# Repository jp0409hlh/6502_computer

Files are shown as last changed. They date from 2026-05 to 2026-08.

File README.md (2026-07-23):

# JP6502 computer

Warning: This repo is still early in development

## Hardware
**Warning** : This section is still under development, do not expect anything to work.
This folder contains the schematics and pcb files for this project.
### main_computer
This folder constains the schematics and pcb files for the JP6502 motherboard.
### others
Future plans : Floppy disk controller expansion card, SD card interface expansion card, ESP32 network expansion card.

## Software
**Warning** : This section is still under development, do not expect anything to work.
This folder contains softwares I wrote for this computer, mainly the OS.

## Credits

+ [Ben eater](http://www.youtube.com/@BenEater) - for the 6502 Youtube series
+ [krallja](http://www.youtube.com/@krallja) - for the [tutorial](https://www.youtube.com/watch?v=0QleiL-WdyM) of interfacing the Tms9918
+ [Doctor Volt](http://www.youtube.com/@DoctorVolt) - for the [tutorial](https://www.youtube.com/watch?v=smgGB_CsXns) of how to connect the Tms9918 to an Arduino, which helped me test my chip
+ [tomcircuit](https://hackaday.io/hacker/1679-tomcircuit) - for the [design](https://hackaday.io/project/160851-tms9918-vdp-with-sram-video-memory) of tms9918 SRAM replacement 
+ [mike's software blog](https://mike42.me/blog/) - for the inspiration of the code for xmodem
+ [sillycowvalley](https://github.com/sillycowvalley) - for the inspiration the [kernel](https://github.com/sillycowvalley/Hopper) 
+ [r/beneater community](https://www.reddit.com/r/beneater/)

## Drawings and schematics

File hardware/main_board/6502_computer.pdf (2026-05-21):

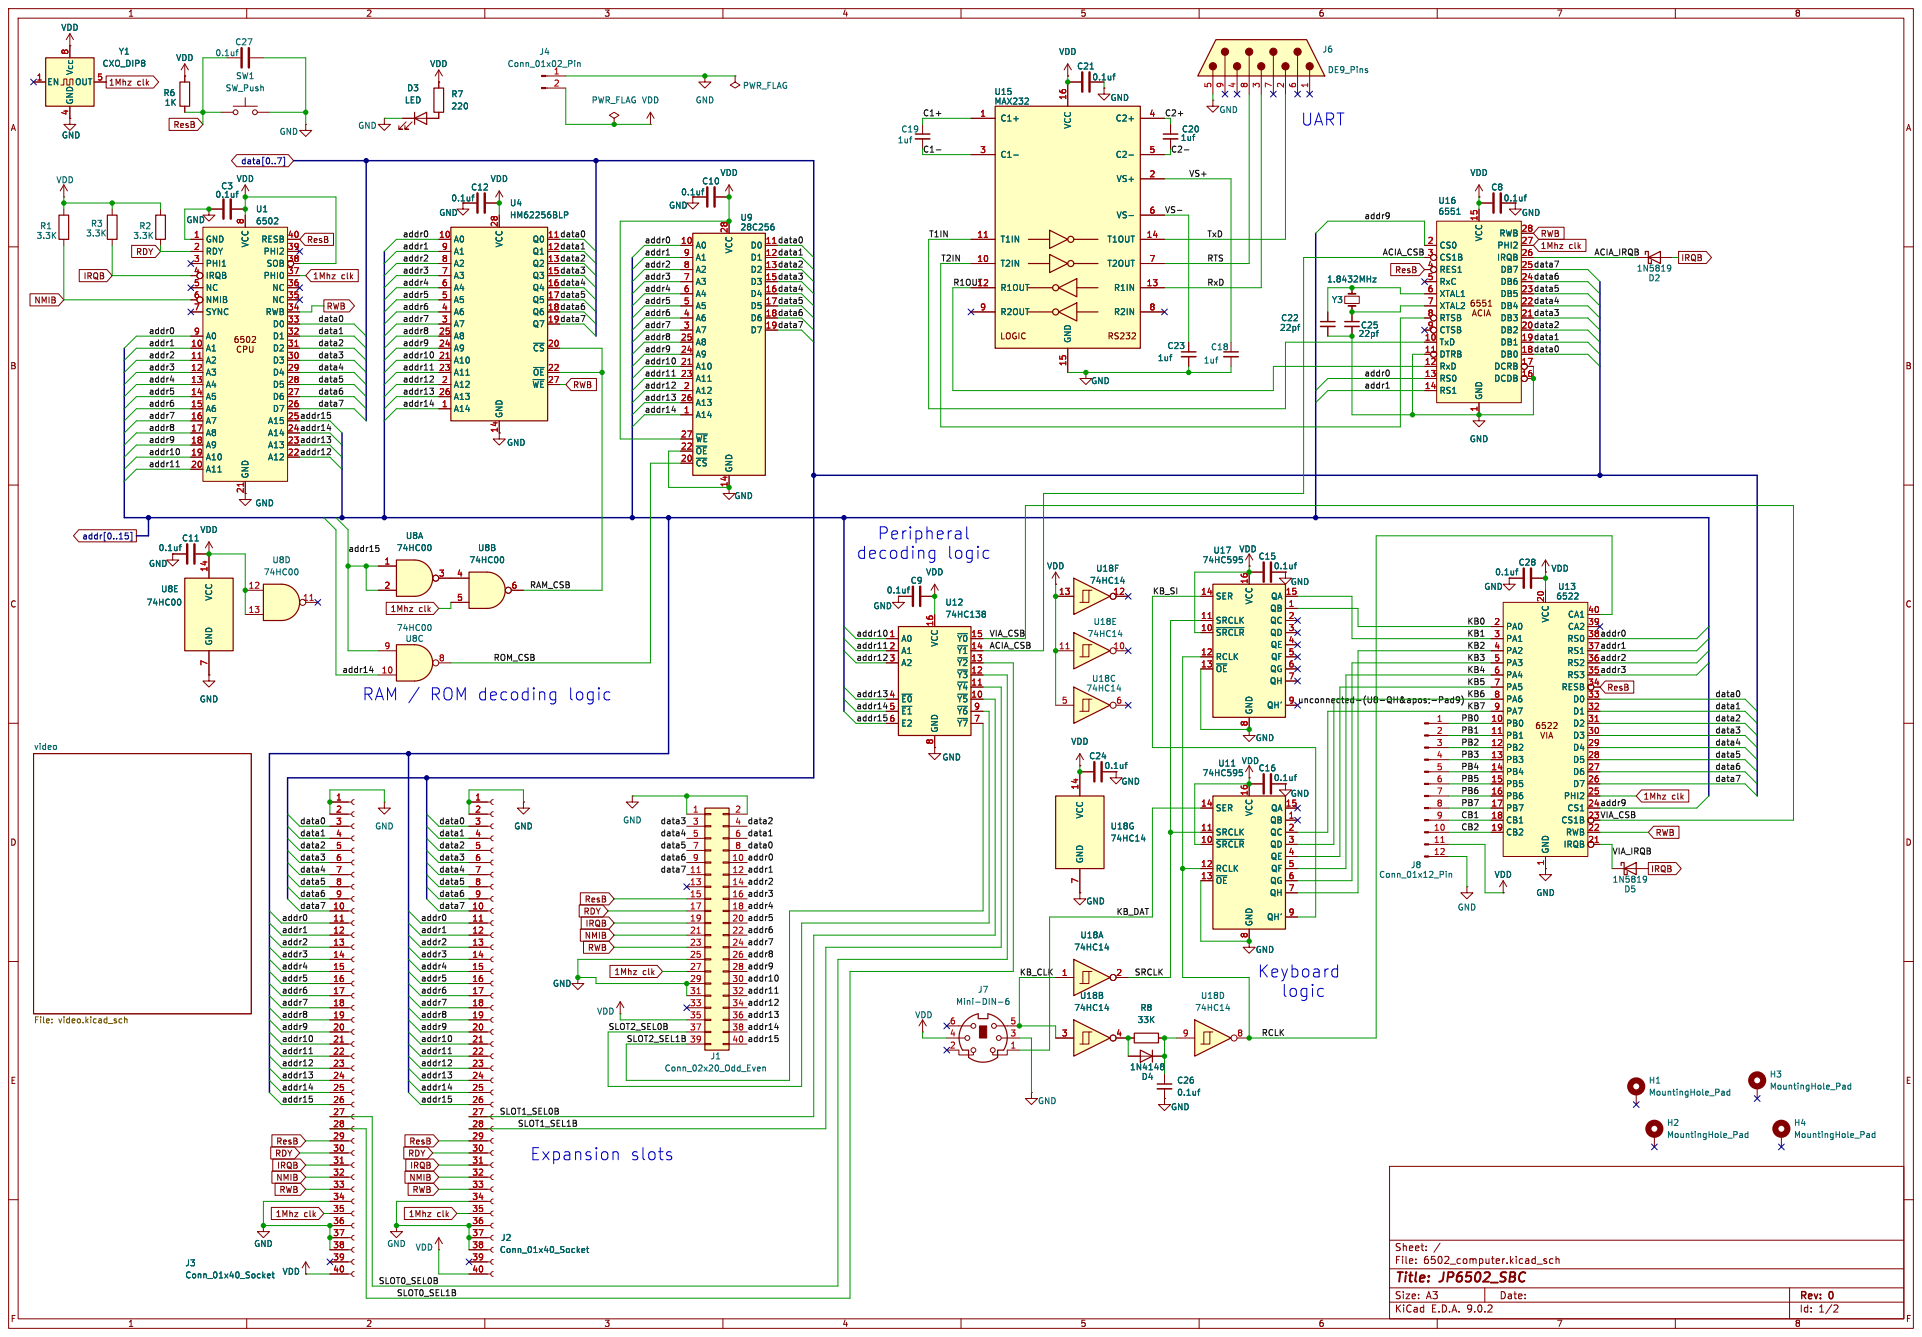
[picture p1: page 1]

8 GND 21 RESB 40 PHI2 39 SOB 38 PHI0 37 NC 36 NC 35 RWB 34 D0 33 D1 32 D2 31 D3 30 D4 29 D5 28 D6 27 D7 26 A15 25 A14 24 A13 23 A12 22 U1

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

8 QA 15 QB 1 QC 2 QD 3 QE 4 QF 5 QG 6 QH 7 QH' 9 GND

RAM / ROM decoding logic

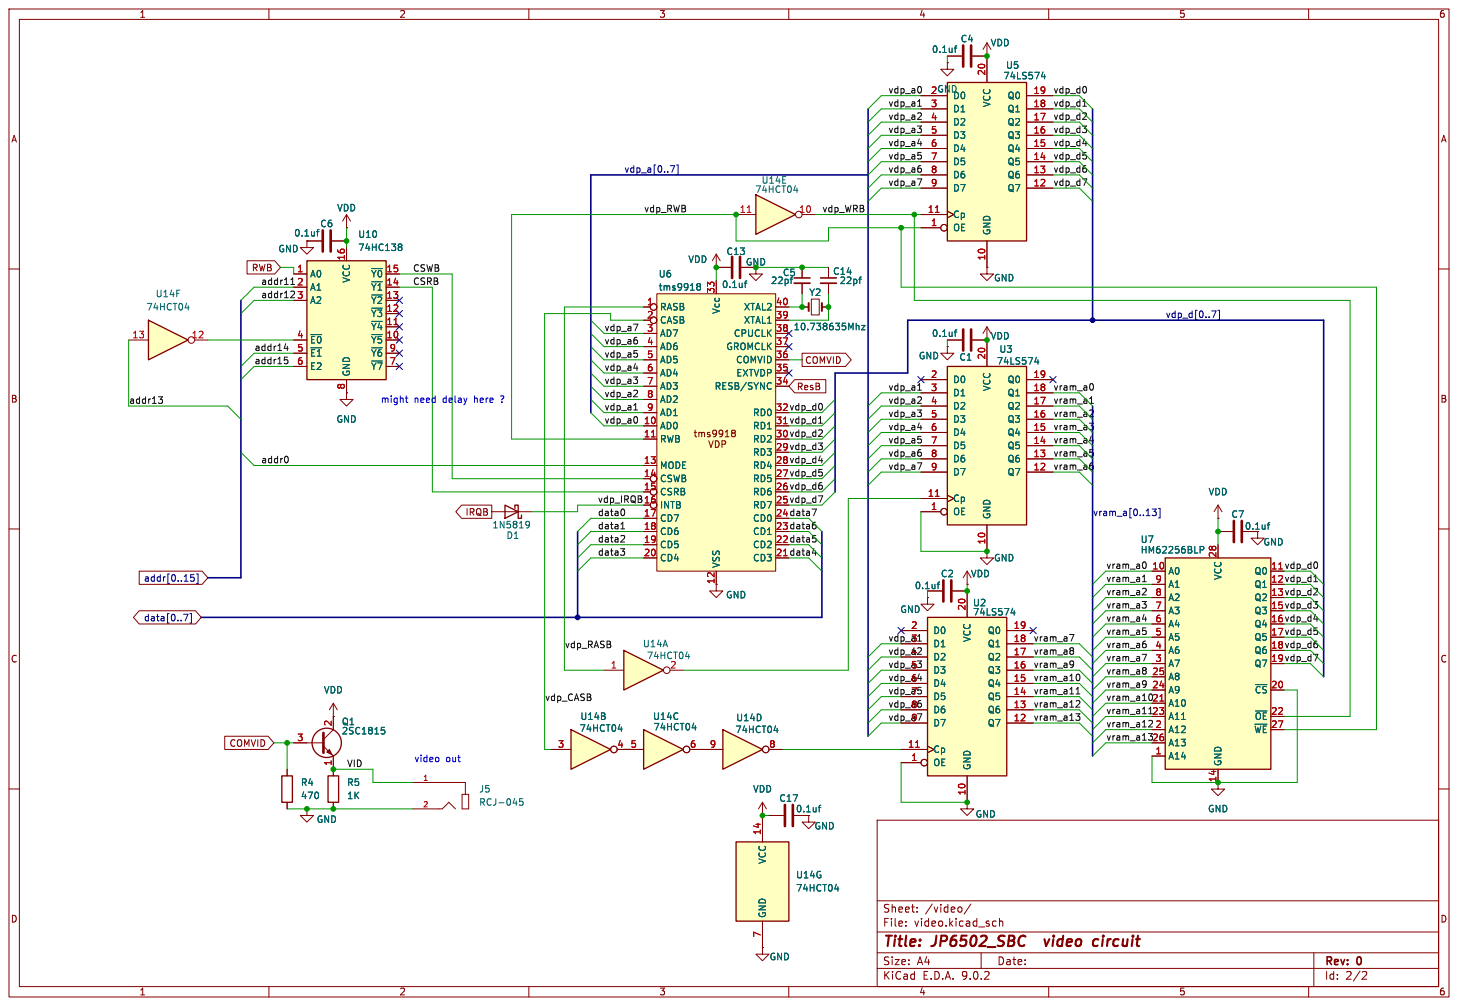
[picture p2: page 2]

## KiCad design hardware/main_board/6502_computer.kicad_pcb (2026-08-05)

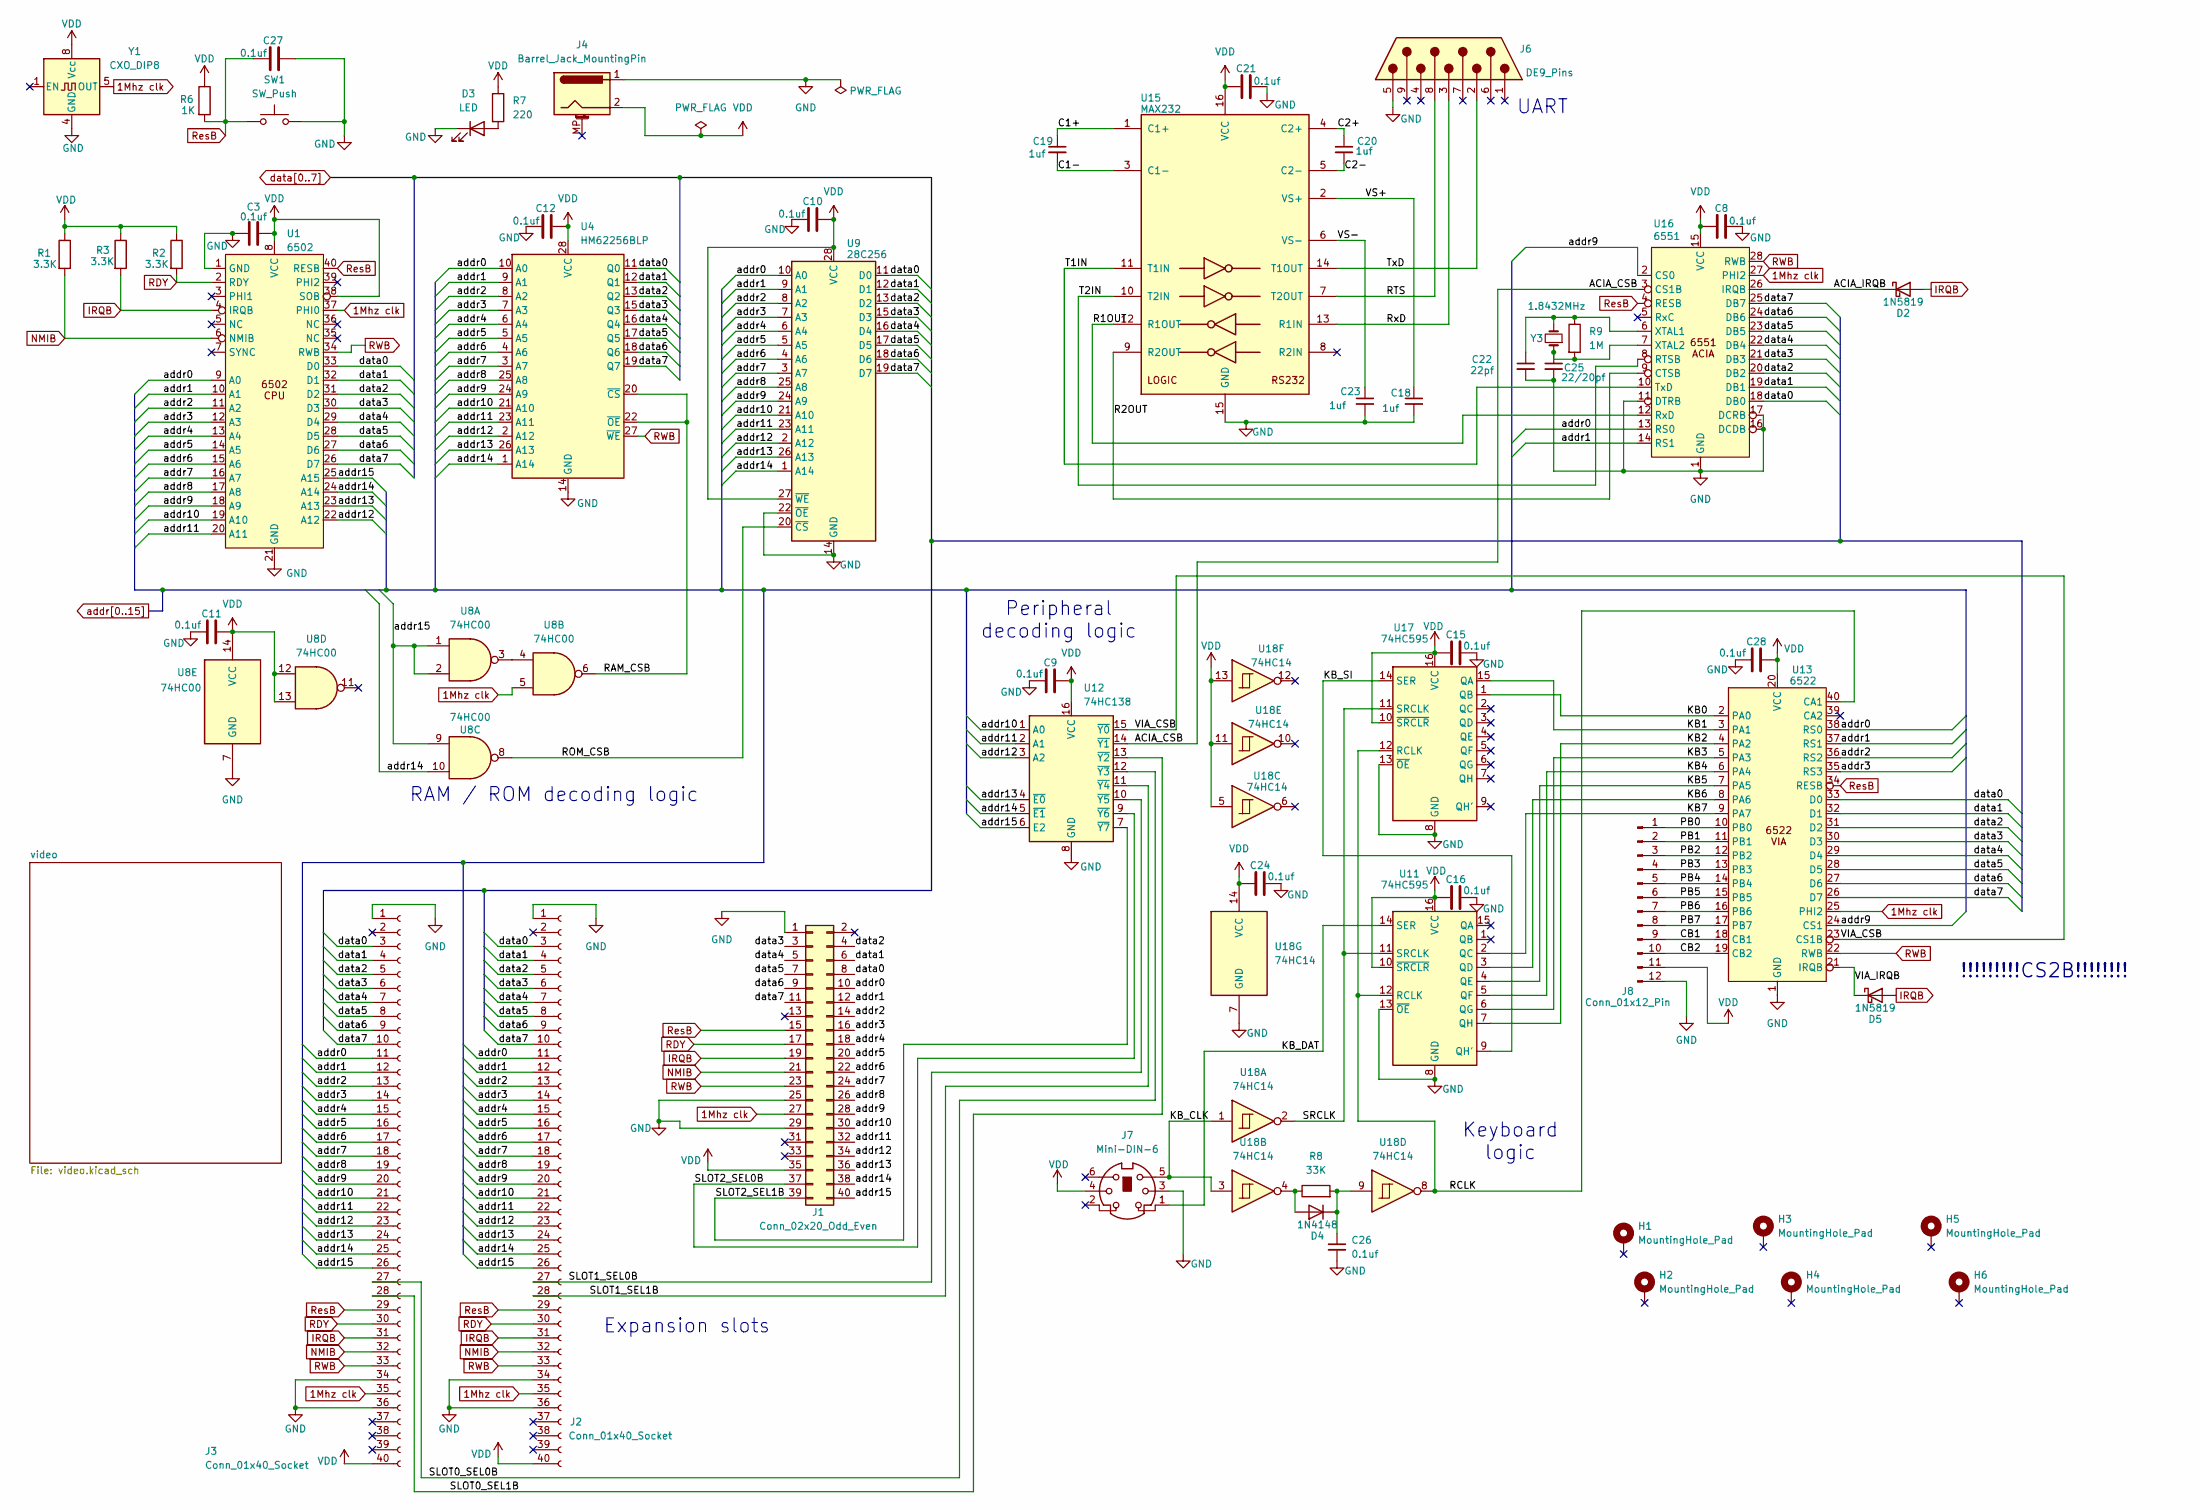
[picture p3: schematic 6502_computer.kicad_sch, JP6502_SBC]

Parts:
C3, C8, C9, C10, C11, C12, C15, C16, C21, C24, C26, C27, C28: 0.1uf; C_Disc_D5.0mm_W2.5mm_P2.50mm
C18, C19, C20, C23: 1uf; C_Disc_D5.1mm_W3.2mm_P5.00mm
C22: 22pf; C_Disc_D5.0mm_W2.5mm_P2.50mm
C25: 22/20pf; C_Disc_D5.0mm_W2.5mm_P2.50mm
D2, D5: 1N5819; D_DO-41_SOD81_P10.16mm_Horizontal
D3: LED; LED_D3.0mm
D4: 1N4148; D_DO-35_SOD27_P7.62mm_Horizontal
H1, H2, H3, H4, H5, H6: MountingHole_Pad; MountingHole_3.2mm_M3_ISO7380_Pad
J1: Conn_02x20_Odd_Even; IDC-Header_2x20_P2.54mm_Vertical
J2, J3: Conn_01x40_Socket; PinSocket_1x40_P2.54mm_Vertical
J4: Barrel_Jack_MountingPin; BarrelJack_Horizontal
J6: DE9_Pins; DSUB-9_Socket_Horizontal_P2.77x2.84mm_EdgePinOffset7.70mm_H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
J7: Mini-DIN-6; TE_5749180-1
J8: Conn_01x12_Pin; PinHeader_1x12_P2.54mm_Horizontal
R1, R2, R3: 3.3K; R_Axial_DIN0207_L6.3mm_D2.5mm_P10.16mm_Horizontal
R6: 1K; R_Axial_DIN0207_L6.3mm_D2.5mm_P10.16mm_Horizontal
R7: 220; R_Axial_DIN0207_L6.3mm_D2.5mm_P10.16mm_Horizontal
R8: 33K; R_Axial_DIN0207_L6.3mm_D2.5mm_P10.16mm_Horizontal
R9: 1M; R_Axial_DIN0207_L6.3mm_D2.5mm_P10.16mm_Horizontal
SW1: SW_Push; SW_PUSH_6mm_H8mm
U1: 6502; DIP-40_W15.24mm_Socket_LongPads
U4: HM62256BLP; DIP-28_W15.24mm_Socket_LongPads
U8: 74HC00; DIP-14_W7.62mm_Socket_LongPads
U9: 28C256; DIP_Socket-28_W11.9_W12.7_W15.24_W17.78_W18.5_3M_228-1277-0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
U11, U17: 74HC595; DIP-16_W7.62mm_Socket_LongPads
U12: 74HC138; DIP-16_W7.62mm_Socket_LongPads
U13: 6522; DIP-40_W15.24mm_Socket_LongPads
U15: MAX232; DIP-16_W7.62mm_Socket_LongPads
U16: 6551; DIP-28_W15.24mm_Socket_LongPads
U18: 74HC14; DIP-14_W7.62mm_Socket_LongPads
Y1: CXO_DIP8; Oscillator_DIP-8
Y3: 1.8432MHz; Crystal_HC18-U_Vertical

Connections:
1Mhz clk: J1.27, J2.35, J3.35, U1.37 (PHI0), U8.5, U13.25 (PHI2), U16.27 (PHI2), Y1.5 (OUT)
/ACIA_CSB: U12.14 (~Y1), U16.3 (CS1B)
/ACIA_IRQB: D2.1 (K), U16.26 (IRQB)
/C1+: C19.1, U15.1 (C1+)
/C1-: C19.2, U15.3 (C1-)
/C2+: C20.1, U15.4 (C2+)
/C2-: C20.2, U15.5 (C2-)
/CB1: J8.9, U13.18 (CB1)
/CB2: J8.10, U13.19 (CB2)
/KB0: U13.2 (PA0), U17.1 (QB)
/KB1: U13.3 (PA1), U17.15 (QA)
/KB2: U11.7 (QH), U13.4 (PA2)
/KB3: U11.6 (QG), U13.5 (PA3)
/KB4: U11.5 (QF), U13.6 (PA4)
/KB5: U11.4 (QE), U13.7 (PA5)
/KB6: U11.3 (QD), U13.8 (PA6)
/KB7: U11.2 (QC), U13.9 (PA7)
/KB_CLK: J7.5, U18.1, U18.3
/KB_DAT: J7.1, U11.14 (SER)
/KB_SI: U11.9 (QH'), U17.14 (SER)
/PB0: J8.1, U13.10 (PB0)
/PB1: J8.2, U13.11 (PB1)
/PB2: J8.3, U13.12 (PB2)
/PB3: J8.4, U13.13 (PB3)
/PB4: J8.5, U13.14 (PB4)
/PB5: J8.6, U13.15 (PB5)
/PB6: J8.7, U13.16 (PB6)
/PB7: J8.8, U13.17 (PB7)
/R1OUT: U15.12 (R1OUT), U16.12 (RxD)
/R2OUT: U15.9 (R2OUT), U16.9 (CTSB)
/RAM_CSB: U4.20 (~CS), U4.22 (~OE), U8.6
/RCLK: U11.12 (RCLK), U13.40 (CA1), U17.12 (RCLK), U18.8
/ROM_CSB: U8.8, U9.20 (~CS)
/RTS: J6.8, U15.7 (T2OUT)
/RxD: J6.3, U15.13 (R1IN)
/SLOT0_SEL0B: J3.27, U12.12 (~Y3)
/SLOT0_SEL1B: J3.28, U12.13 (~Y2)
/SLOT1_SEL0B: J2.27, U12.10 (~Y5)
/SLOT1_SEL1B: J2.28, U12.11 (~Y4)
/SLOT2_SEL0B: J1.37, U12.9 (~Y6)
/SLOT2_SEL1B: J1.39, U12.7 (~Y7)
/SRCLK: U11.11 (SRCLK), U17.11 (SRCLK), U18.2
/T1IN: U15.11 (T1IN), U16.10 (TxD)
/T2IN: U15.10 (T2IN), U16.8 (RTSB)
/TxD: J6.2, U15.14 (T1OUT)
/VIA_CSB: U12.15 (~Y0), U13.23 (CS1B)
/VIA_IRQB: D5.1 (K), U13.21 (IRQB)
/VS+: C18.1, U15.2 (VS+)
/VS-: C23.1, U15.6 (VS-)
GND: C3.1, C8.2, C9.1, C10.1, C11.1, C12.1, C15.2, C16.2, C18.2, C21.2, C22.2, C23.2, C24.2, C25.2, C26.2, C27.2, C28.1, D3.1 (K), J1.1, J1.25, J1.29, J2.1, J2.34, J2.36, J3.1, J3.34, J3.36, J4.1, J6.5, J7.3, J8.12, SW1.2, U1.1 (GND), U1.21 (GND), U4.14 (GND), U8.7 (GND), U9.14 (GND), U9.22 (~OE), U11.8 (GND), U11.13 (~OE), U12.8 (GND), U13.1 (GND), U15.15 (GND), U16.1 (GND), U16.11 (DTRB), U16.16 (DCDB), U16.17 (DCRB), U17.8 (GND), U17.13 (~OE), U18.7 (GND), Y1.4 (GND); also elsewhere on the board
IRQB: D2.2 (A), D5.2 (A), J1.19, J2.31, J3.31, R3.2, U1.4 (IRQB); also elsewhere on the board
NMIB: J1.21, J2.32, J3.32, R1.2, U1.6 (NMIB)
unnamed: D3.2 (A), R7.2
unnamed: D4.2 (A), R8.1, U18.4
unnamed: C26.1, D4.1 (K), R8.2, U18.9
unnamed: U8.3, U8.4
unnamed: C22.1, R9.1, U16.6 (XTAL1), Y3.2
unnamed: C25.1, R9.2, U16.7 (XTAL2), Y3.1
RDY: J1.17, J2.30, J3.30, R2.2, U1.2 (RDY)
RWB: J1.23, J2.33, J3.33, U1.34 (RWB), U4.27 (~WE), U13.22 (RWB), U16.28 (RWB); also elsewhere on the board
ResB: C27.1, J1.15, J2.29, J3.29, R6.2, SW1.1, U1.40 (RESB), U13.34 (RESB), U16.4 (RESB); also elsewhere on the board
VDD: C3.2, C8.1, C9.2, C10.2, C11.2, C12.2, C15.1, C16.1, C21.1, C24.1, C28.2, J1.35, J2.40, J3.40, J4.2, J7.4, J8.11, R1.1, R2.1, R3.1, R6.1, R7.1, U1.8 (VCC), U1.38 (SOB), U4.28 (VCC), U8.12, U8.13, U8.14 (VCC), U9.27 (~WE), U9.28 (VCC), U11.10 (~SRCLR), U11.16 (VCC), U12.16 (VCC), U13.20 (VCC), U15.16 (VCC), U16.15 (VCC), U17.10 (~SRCLR), U17.16 (VCC), U18.5, U18.11, U18.13, U18.14 (VCC), Y1.8 (Vcc); also elsewhere on the board
addr0: J1.10, J2.11, J3.11, U1.9 (A0), U4.10 (A0), U9.10 (A0), U13.38 (RS0), U16.13 (RS0); also elsewhere on the board
addr1: J1.12, J2.12, J3.12, U1.10 (A1), U4.9 (A1), U9.9 (A1), U13.37 (RS1), U16.14 (RS1)
addr2: J1.14, J2.13, J3.13, U1.11 (A2), U4.8 (A2), U9.8 (A2), U13.36 (RS2)
addr3: J1.16, J2.14, J3.14, U1.12 (A3), U4.7 (A3), U9.7 (A3), U13.35 (RS3)
addr4: J1.18, J2.15, J3.15, U1.13 (A4), U4.6 (A4), U9.6 (A4)
addr5: J1.20, J2.16, J3.16, U1.14 (A5), U4.5 (A5), U9.5 (A5)
addr6: J1.22, J2.17, J3.17, U1.15 (A6), U4.4 (A6), U9.4 (A6)
addr7: J1.24, J2.18, J3.18, U1.16 (A7), U4.3 (A7), U9.3 (A7)
addr8: J1.26, J2.19, J3.19, U1.17 (A8), U4.25 (A8), U9.25 (A8)
addr9: J1.28, J2.20, J3.20, U1.18 (A9), U4.24 (A9), U9.24 (A9), U13.24 (CS1), U16.2 (CS0)
addr10: J1.30, J2.21, J3.21, U1.19 (A10), U4.21 (A10), U9.21 (A10), U12.1 (A0)
addr11: J1.32, J2.22, J3.22, U1.20 (A11), U4.23 (A11), U9.23 (A11), U12.2 (A1); also elsewhere on the board
addr12: J1.34, J2.23, J3.23, U1.22 (A12), U4.2 (A12), U9.2 (A12), U12.3 (A2); also elsewhere on the board
addr13: J1.36, J2.24, J3.24, U1.23 (A13), U4.26 (A13), U9.26 (A13), U12.4 (~E0); also elsewhere on the board
addr14: J1.38, J2.25, J3.25, U1.24 (A14), U4.1 (A14), U8.10, U9.1 (A14), U12.5 (~E1); also elsewhere on the board
addr15: J1.40, J2.26, J3.26, U1.25 (A15), U8.1, U8.2, U8.9, U12.6 (E2); also elsewhere on the board
data0: J1.8, J2.3, J3.3, U1.33 (D0), U4.11 (Q0), U9.11 (D0), U13.33 (D0), U16.18 (DB0); also elsewhere on the board
data1: J1.6, J2.4, J3.4, U1.32 (D1), U4.12 (Q1), U9.12 (D1), U13.32 (D1), U16.19 (DB1); also elsewhere on the board
data2: J1.4, J2.5, J3.5, U1.31 (D2), U4.13 (Q2), U9.13 (D2), U13.31 (D2), U16.20 (DB2); also elsewhere on the board
data3: J1.3, J2.6, J3.6, U1.30 (D3), U4.15 (Q3), U9.15 (D3), U13.30 (D3), U16.21 (DB3); also elsewhere on the board
data4: J1.5, J2.7, J3.7, U1.29 (D4), U4.16 (Q4), U9.16 (D4), U13.29 (D4), U16.22 (DB4); also elsewhere on the board
data5: J1.7, J2.8, J3.8, U1.28 (D5), U4.17 (Q5), U9.17 (D5), U13.28 (D5), U16.23 (DB5); also elsewhere on the board
data6: J1.9, J2.9, J3.9, U1.27 (D6), U4.18 (Q6), U9.18 (D6), U13.27 (D6), U16.24 (DB6); also elsewhere on the board
data7: J1.11, J2.10, J3.10, U1.26 (D7), U4.19 (Q7), U9.19 (D7), U13.26 (D7), U16.25 (DB7); also elsewhere on the board

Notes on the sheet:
!!!!!!!!!CS2B!!!!!!!!
UART
RAM / ROM decoding logic
Expansion slots
Keyboard logic
Peripheral decoding logic

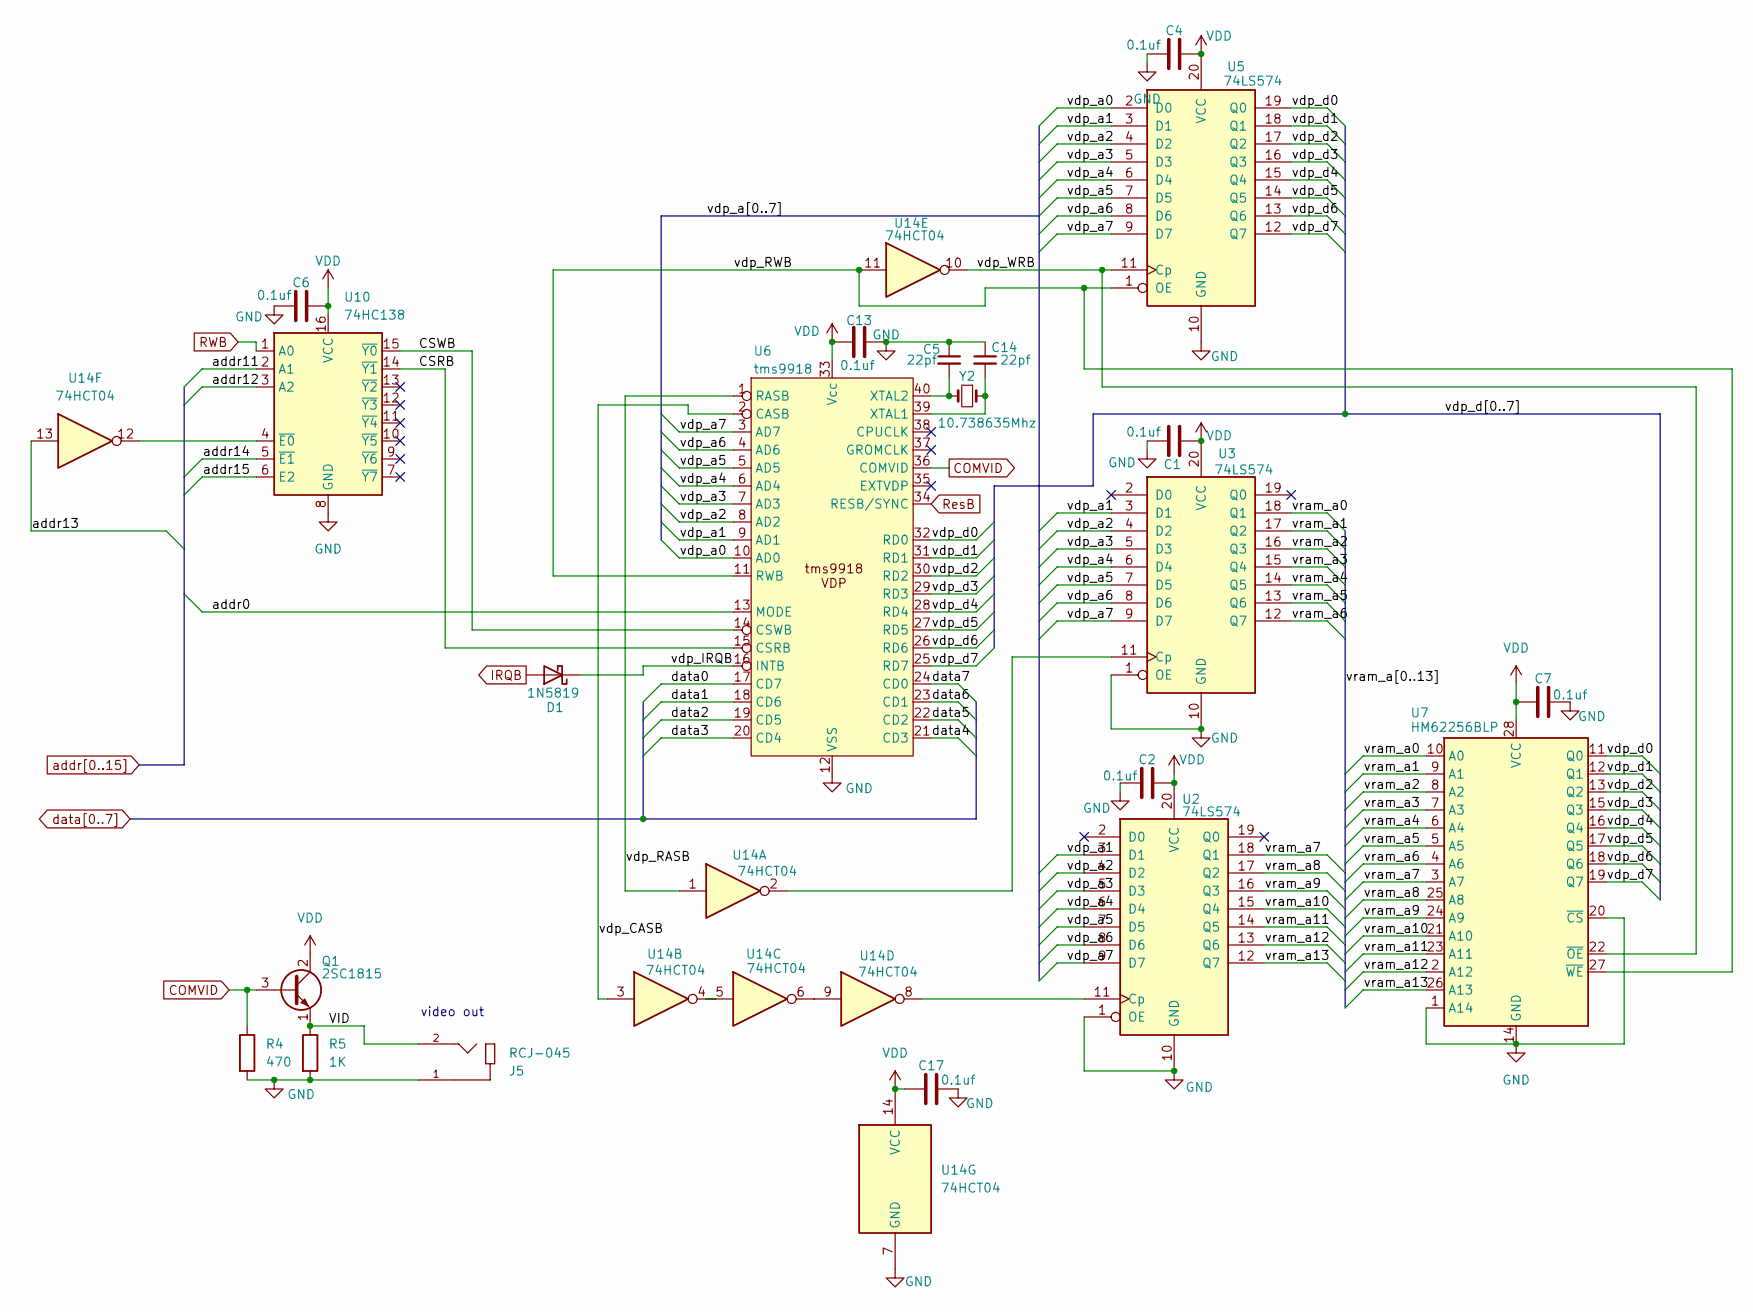
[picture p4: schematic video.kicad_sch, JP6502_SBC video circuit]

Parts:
C1, C2, C4, C6, C7, C13, C17: 0.1uf; C_Disc_D5.0mm_W2.5mm_P2.50mm
C5, C14: 22pf; C_Disc_D5.0mm_W2.5mm_P2.50mm
D1: 1N5819; D_DO-41_SOD81_P10.16mm_Horizontal
J5: RCJ-045; CUI_RCJ-045
Q1: 2SC1815; TO-92_HandSolder
R4: 470; R_Axial_DIN0207_L6.3mm_D2.5mm_P10.16mm_Horizontal
R5: 1K; R_Axial_DIN0207_L6.3mm_D2.5mm_P10.16mm_Horizontal
U2, U3, U5: 74LS574; DIP-20_W7.62mm_Socket_LongPads
U6: tms9918; DIP-40_W15.24mm_Socket_LongPads
U7: HM62256BLP; DIP-28_W15.24mm_LongPads
U10: 74HC138; DIP-16_W7.62mm_Socket_LongPads
U14: 74HCT04; DIP-14_W7.62mm_Socket_LongPads
Y2: 10.738635Mhz; Crystal_HC18-U_Vertical

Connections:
/video/CSRB: U6.15 (CSRB), U10.14 (~Y1)
/video/CSWB: U6.14 (CSWB), U10.15 (~Y0)
/video/VID: J5.2, Q1.1 (E), R5.1
/video/vdp_CASB: U6.2 (CASB), U14.3
/video/vdp_IRQB: D1.1 (K), U6.16 (INTB)
/video/vdp_RASB: U6.1 (RASB), U14.1
/video/vdp_RWB: U5.1 (OE), U6.11 (RWB), U7.27 (~WE), U14.11
/video/vdp_WRB: U5.11 (Cp), U7.22 (~OE), U14.10
/video/vdp_a0: U5.2 (D0), U6.10 (AD0)
/video/vdp_a1: U2.3 (D1), U3.3 (D1), U5.3 (D1), U6.9 (AD1)
/video/vdp_a2: U2.4 (D2), U3.4 (D2), U5.4 (D2), U6.8 (AD2)
/video/vdp_a3: U2.5 (D3), U3.5 (D3), U5.5 (D3), U6.7 (AD3)
/video/vdp_a4: U2.6 (D4), U3.6 (D4), U5.6 (D4), U6.6 (AD4)
/video/vdp_a5: U2.7 (D5), U3.7 (D5), U5.7 (D5), U6.5 (AD5)
/video/vdp_a6: U2.8 (D6), U3.8 (D6), U5.8 (D6), U6.4 (AD6)
/video/vdp_a7: U2.9 (D7), U3.9 (D7), U5.9 (D7), U6.3 (AD7)
/video/vdp_d0: U5.19 (Q0), U6.32 (RD0), U7.11 (Q0)
/video/vdp_d1: U5.18 (Q1), U6.31 (RD1), U7.12 (Q1)
/video/vdp_d2: U5.17 (Q2), U6.30 (RD2), U7.13 (Q2)
/video/vdp_d3: U5.16 (Q3), U6.29 (RD3), U7.15 (Q3)
/video/vdp_d4: U5.15 (Q4), U6.28 (RD4), U7.16 (Q4)
/video/vdp_d5: U5.14 (Q5), U6.27 (RD5), U7.17 (Q5)
/video/vdp_d6: U5.13 (Q6), U6.26 (RD6), U7.18 (Q6)
/video/vdp_d7: U5.12 (Q7), U6.25 (RD7), U7.19 (Q7)
/video/vram_a0: U3.18 (Q1), U7.10 (A0)
/video/vram_a1: U3.17 (Q2), U7.9 (A1)
/video/vram_a2: U3.16 (Q3), U7.8 (A2)
/video/vram_a3: U3.15 (Q4), U7.7 (A3)
/video/vram_a4: U3.14 (Q5), U7.6 (A4)
/video/vram_a5: U3.13 (Q6), U7.5 (A5)
/video/vram_a6: U3.12 (Q7), U7.4 (A6)
/video/vram_a7: U2.18 (Q1), U7.3 (A7)
/video/vram_a8: U2.17 (Q2), U7.25 (A8)
/video/vram_a9: U2.16 (Q3), U7.24 (A9)
/video/vram_a10: U2.15 (Q4), U7.21 (A10)
/video/vram_a11: U2.14 (Q5), U7.23 (A11)
/video/vram_a12: U2.13 (Q6), U7.2 (A12)
/video/vram_a13: U2.12 (Q7), U7.26 (A13)
COMVID: Q1.3 (B), R4.1, U6.36 (COMVID)
GND: C1.1, C2.1, C4.1, C5.1, C6.1, C7.2, C13.2, C14.1, C17.2, J5.1, R4.2, R5.2, U2.1 (OE), U2.10 (GND), U3.1 (OE), U3.10 (GND), U5.10 (GND), U6.12 (VSS), U7.1 (A14), U7.14 (GND), U7.20 (~CS), U10.8 (GND), U14.7 (GND); also elsewhere on the board
IRQB: D1.2 (A); also elsewhere on the board
unnamed: U2.11 (Cp), U14.8
unnamed: U3.11 (Cp), U14.2
unnamed: C14.2, U6.39 (XTAL1), Y2.1
unnamed: C5.2, U6.40 (XTAL2), Y2.2
unnamed: U10.4 (~E0), U14.12
unnamed: U14.4, U14.5
unnamed: U14.6, U14.9
RWB: U10.1 (A0); also elsewhere on the board
ResB: U6.34 (RESB/SYNC); also elsewhere on the board
VDD: C1.2, C2.2, C4.2, C6.2, C7.1, C13.1, C17.1, Q1.2 (C), U2.20 (VCC), U3.20 (VCC), U5.20 (VCC), U6.33 (Vcc), U7.28 (VCC), U10.16 (VCC), U14.14 (VCC); also elsewhere on the board
addr0: U6.13 (MODE); also elsewhere on the board
addr11: U10.2 (A1); also elsewhere on the board
addr12: U10.3 (A2); also elsewhere on the board
addr13: U14.13; also elsewhere on the board
addr14: U10.5 (~E1); also elsewhere on the board
addr15: U10.6 (E2); also elsewhere on the board
data0: U6.17 (CD7); also elsewhere on the board
data1: U6.18 (CD6); also elsewhere on the board
data2: U6.19 (CD5); also elsewhere on the board
data3: U6.20 (CD4); also elsewhere on the board
data4: U6.21 (CD3); also elsewhere on the board
data5: U6.22 (CD2); also elsewhere on the board
data6: U6.23 (CD1); also elsewhere on the board
data7: U6.24 (CD0); also elsewhere on the board

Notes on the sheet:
video out

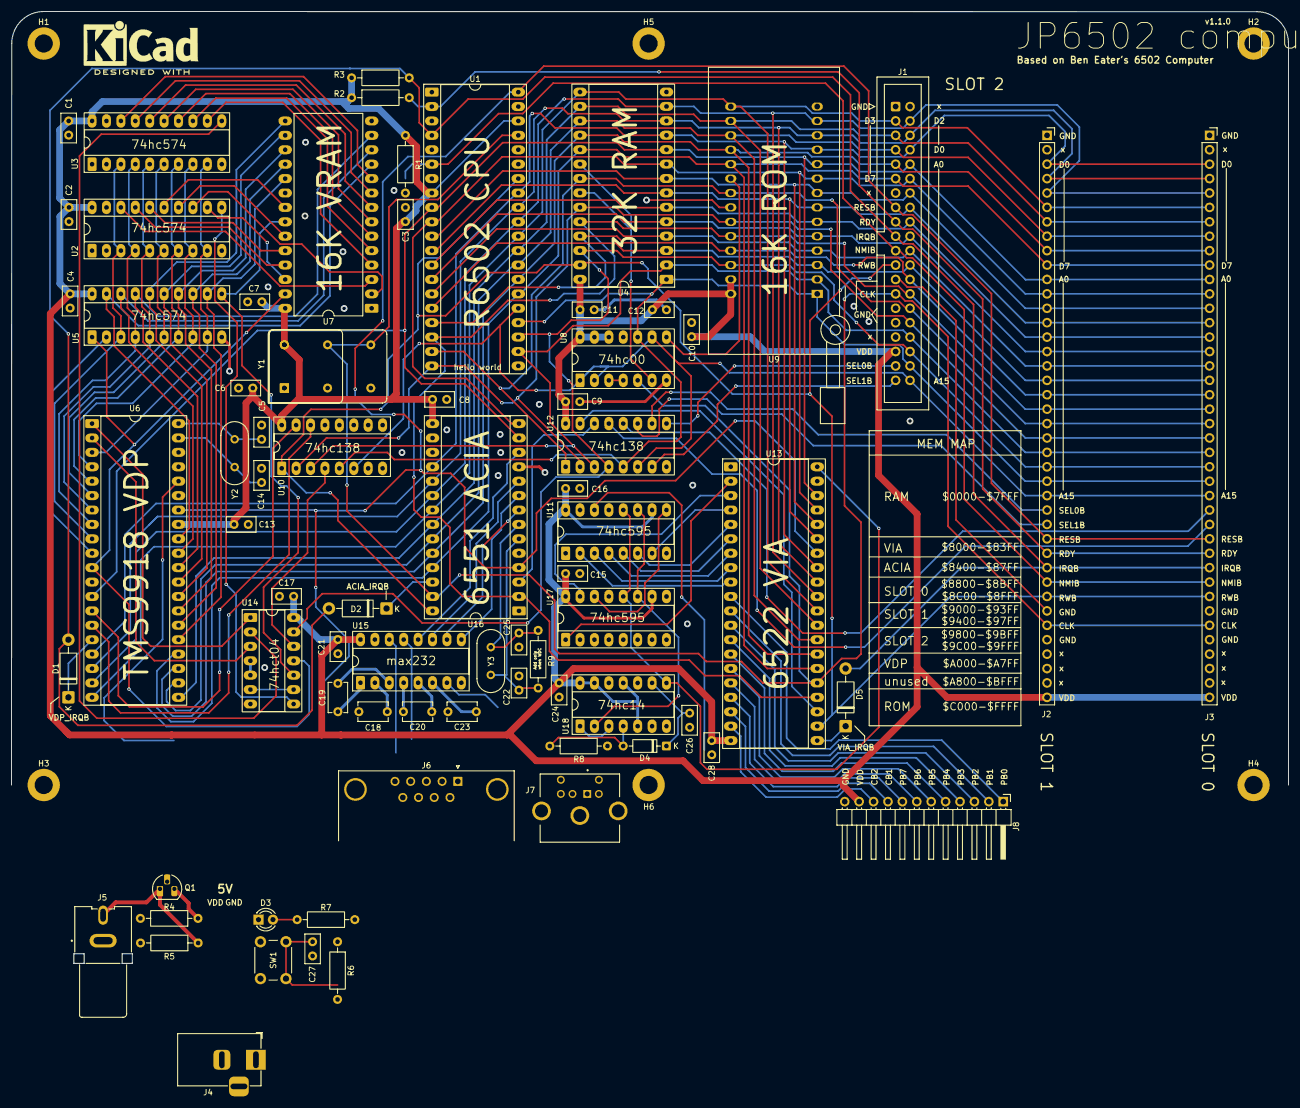
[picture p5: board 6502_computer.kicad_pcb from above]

Board: 2 copper layers, 225.1 x 167.8 mm, 80 parts (0 on the bottom side), 132 nets.

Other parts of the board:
kicad_logo: KiCad-Logo2_8mm_SilkScreen

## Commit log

2026-05-21 Updated gitignore
    [freerouting.dsn, temp-freerouting.dsn]
2026-05-21 Generated gerber fill and pdf schematics
    [6502_computer-B_Cu.gbr, 6502_computer-B_Mask.gbr, 6502_computer-B_Paste.gbr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]
2026-05-24 updated pcb and sch
    [6502_computer.kicad_pcb, 6502_computer.kicad_sch]
2026-07-21 Adds stuff
    [6502_computer-B_Cu.gbr, 6502_computer-B_Mask.gbr, 6502_computer-B_Paste.gbr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]
2026-07-21 Added control ascii for print syscall
2026-07-24 replace load with rx
    [6502_computer.kicad_pcb, 6502_computer.kicad_sch]
2026-07-30 Added assembler line editor
2026-07-30 Rework project structure
    [os.cfg]
2026-08-02 Added a demo program
    [main.cfg]
